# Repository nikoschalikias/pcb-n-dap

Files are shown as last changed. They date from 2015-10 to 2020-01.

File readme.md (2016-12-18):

Pinout
------

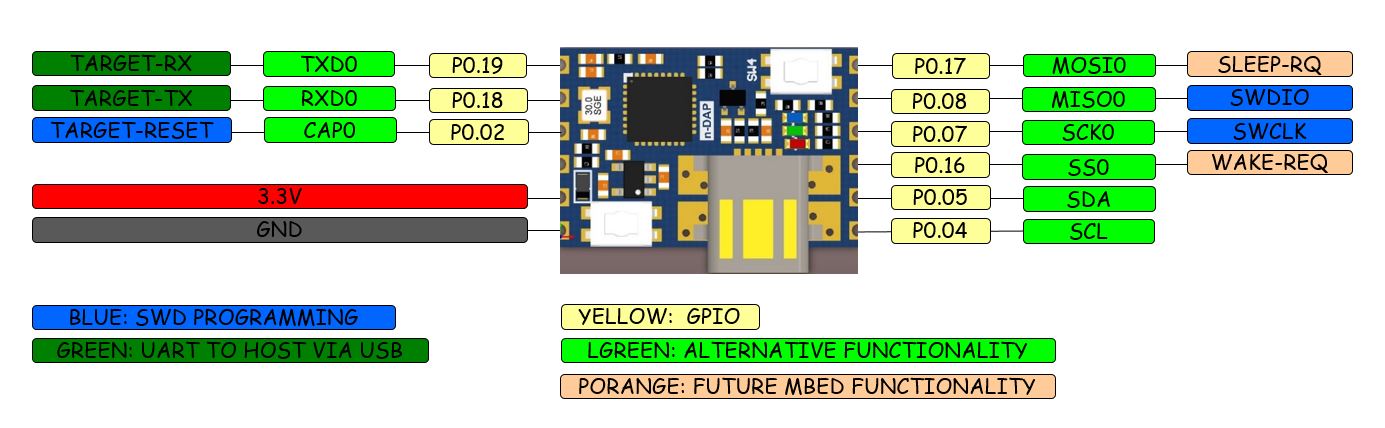
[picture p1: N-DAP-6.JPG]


-   The board has 12 pins, 6 for each side, If the board is used SWD
    only 3 pins for signals and 2 pins for power are needed

Background
----------

LPC11U32 based CMSIS-DAP programming of ARM Cortex devices via SWD.
Appears as a Disk to PC. Tested with mbed firmware.\
Provides **mbed-enable** capability and can be designed-in as an SMD
component or used as external programmer/debuger.\
\
\
\


\
\
\
\
\

Features
--------

<File:N-DAP-3.JPG> <File:N-DAP-2.JPG>

-   Breadboard-able: 1/10 inch connector pitch
-   Solder as SMD component: SMD half pads at 1/10' pitch
-   Robust USB mini connector:

\
\

mbed-enable Firmware
--------------------

### LPC1768

-   [**LPC11U32-Firmware** for communicating with
    LPC1768](https://developer.mbed.org/users/chalikias/code/mbed-HDK/)

\

### LPC812

The same as LPC1768 above\
\
===LPC1114FN28===

-   Firmware to use n-DAP with the non-SMD LPC1114FN28 DIP-28 [Firmware
    LPC1114FN28](https://developer.mbed.org/teams/Switch-Science/wiki/Firmware-LPC1114FN28)

\
===nRF51822===

-   [Seeed studio wiki Arch
    BLE](http://www.seeedstudio.com/wiki/Arch_BLE)
-   [Seeed studio wiki <File:Lpc11u35> nrf51822 if
    mbed.bin.zip](http://www.seeedstudio.com/wiki/File:Lpc11u35_nrf51822_if_mbed.bin.zip)

\
\

Using with mbed-CLI
-------------------

-   Checking the working target setup\

\
\
\* compile\
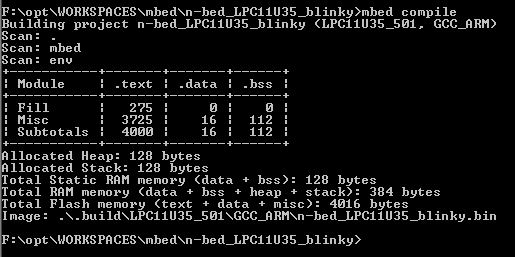
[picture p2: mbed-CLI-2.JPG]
\
\
\* After pressing \[SW4+SW3\], then \[SW3 only\], then \[release
SW3\],CPU is in ISP mode and appears as Disk with name **"CRP
DISABLD"**\
\* Remove previous firmware from CPU flash by deleting the file
**firmware.bin**\
\*The folder should be empty\
\*Then just drag-drop the new compiled .bin to the mbed board. It should
appear as "**firmware.bin**"

\
\

Related articles in this Wiki
-----------------------------

-   []( "wikilink")

\
\

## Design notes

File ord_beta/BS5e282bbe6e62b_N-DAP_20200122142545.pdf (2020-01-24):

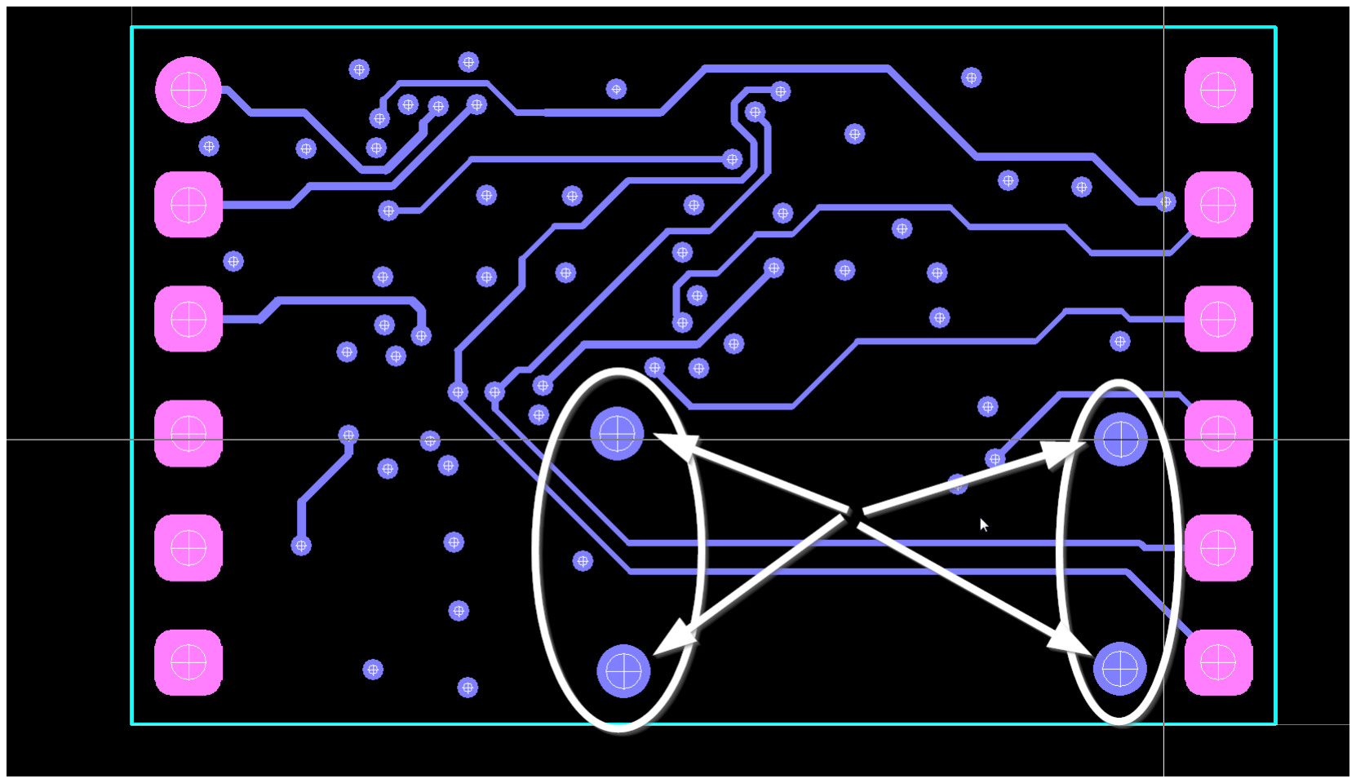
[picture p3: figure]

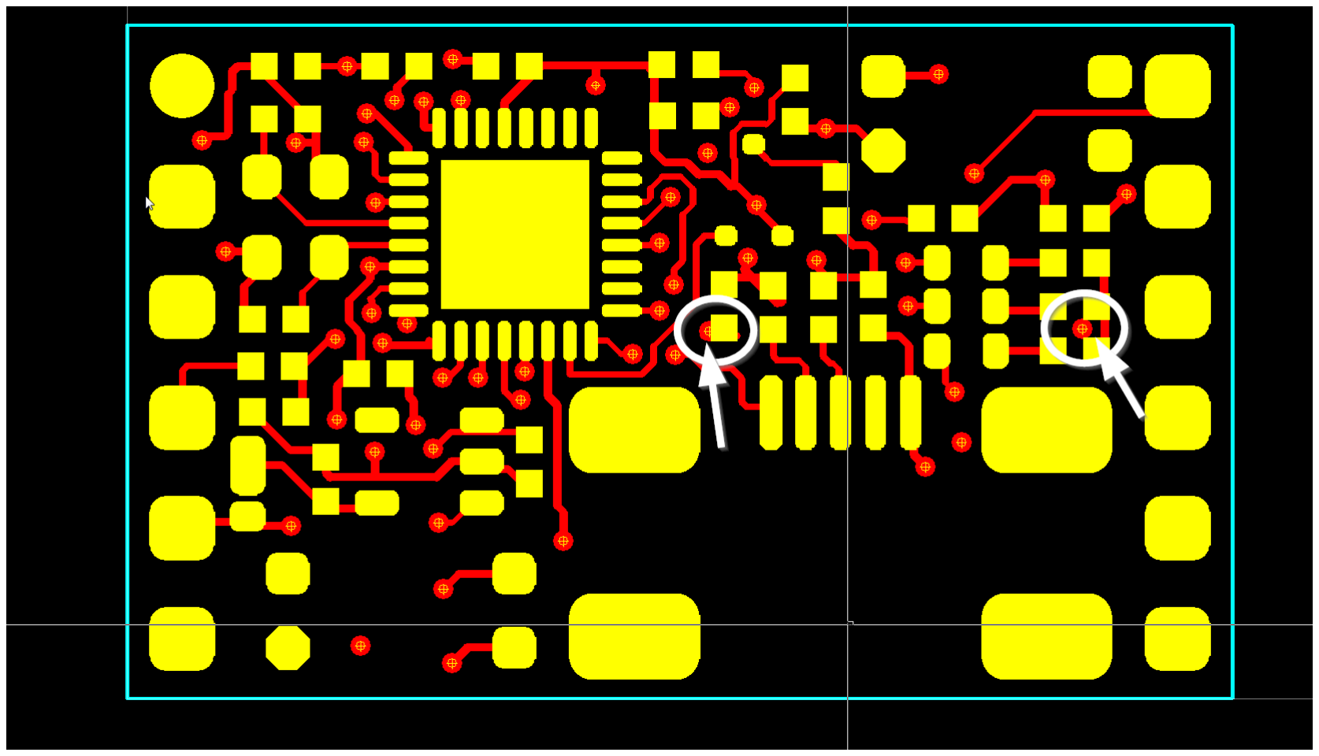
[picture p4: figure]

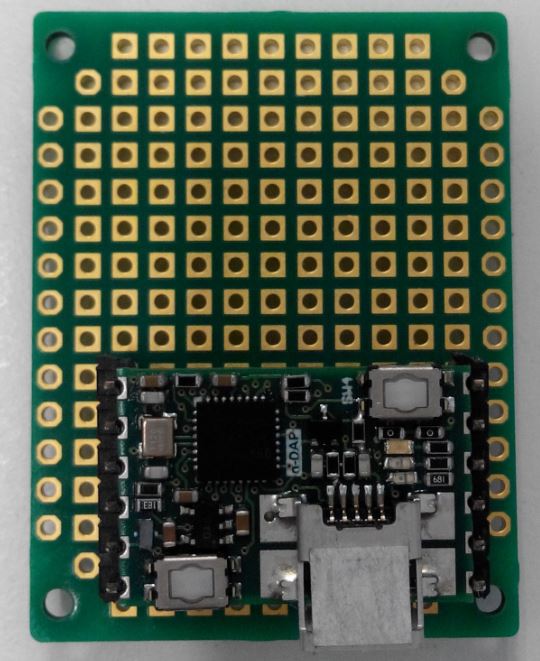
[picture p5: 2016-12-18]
doc/N-DAP-2.JPG

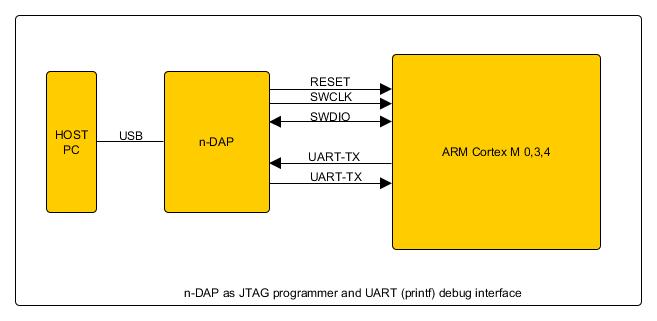
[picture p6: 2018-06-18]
doc/n-dap-programming-block-diagram.jpg

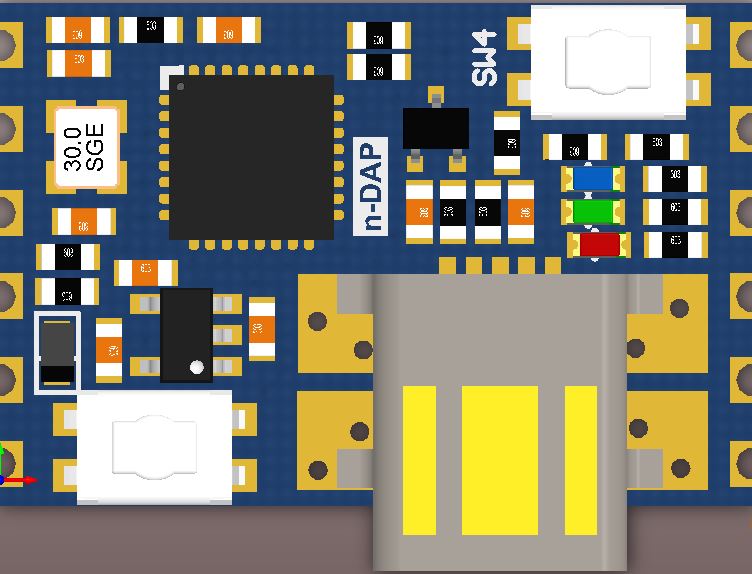
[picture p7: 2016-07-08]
doc/N-DAP-1.JPG

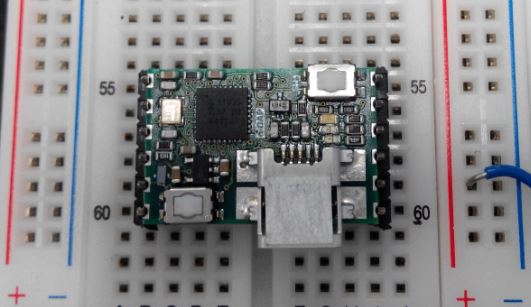
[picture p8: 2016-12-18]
doc/N-DAP-3.JPG

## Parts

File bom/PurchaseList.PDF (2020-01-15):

Item # | Designator | Comment | Footprint | Description | Manufacturer 1 | Manufacturer Part
| | | | | Number 1 | Supplier 1 | | Supplier Stock 1 | Supplier Part Number 1 | Divi der
1 | C1, C4, C5 | 100nF | 0402_CAP | CAPACITOR | Wurth Electronics | 885012105016 | Mouser | EUR | 40946 | 710-885012105016 | 1 | 3 | 108 | 108 | €0.02 | €2.04 | 1
2 | C2, C3 | 18pF | 0402_CAP | CAPACITOR | Walsin Technologies | 0402N180F500CT | Mouser | EUR | 5900 | 791-0402N180F500CT | 1 | 2 | 100 | 100 | €0.04 | €3.59 | 2
3 | C6, C7 | 33pF | 0402_CAP | CAPACITOR | Wurth Electronics | 885012005058 | Mouser | EUR | 34052 | 710-885012005058 | 1 | 2 | 72 | 72 | €0.01 | €1.03 | 3
4 | C8, C10 | 1uF/MLCC | 0402_CAP | CAPACITOR | Taiyo Yuden | JMK105BJ105KP-F | Mouser | EUR | 25442 | 963-JMK105BJ105KP-F | 1 | 2 | 100 | 100 | €0.03 | €2.88 | 4
5 | D1 | LED_RED_0603 | 0603_LED_RED | | Osram Opto | LSQ976-NR-1 | Mouser | EUR | 67675 | 720-LSQ976-NR-1 | 1 | 1 | 100 | 100 | €0.07 | €6.83 | 5
6 | D2 | LED_GRN_0603 | 0603_LED_GRN | | Kingbright | APT1608SGC | Mouser | EUR | 40404 | 604-APT1608SGC | 1 | 1 | 36 | 36 | €0.10 | €3.75 | 6
7 | D3 | LED_BLU_0603 | 0603_LED_BLU | | Osram Opto | LB Q39G-L2OO-35-1 | Mouser | EUR | 58553 | 720-LBQ39GL2N2351 | 1 | 1 | 36 | 36 | €0.27 | €9.70 | 7
8 | D5 | NSR20F30NXT5G | 0603_DIODE-NSR20F30 | SCHOTTKY DIODE 0603 | ON Semiconductor | NSR20F30NXT5G | Mouser | EUR | 115642 | 863-NSR20F30NXT5G | 1.3 | 1 | 36 | 47 | €0.34 | €16.09 | 8
9 | JP2 | USB-MINI-B | USB-MINI-B-HIR-UX60A-MB-5ST-SMALL | | Hirose | UX60A-MB-5ST | Mouser | EUR | 21413 | 798-UX60A-MB-5ST | 1 | 1 | 36 | 36 | €0.67 | €24.06 | 9
10 | Q1 | BSS84,215 | SOT323/SC70-3_SMALL | POWER MOSFET-P SOT23 | Diodes | BSS84W-7-F | Mouser | EUR | 97989 | 621-BSS84W-F | 1 | 1 | 36 | 36 | €0.24 | €8.60 | 10
11 | R1, R3, R4, R9, R14 | 10K | 0402_res | RESISTOR | Vishay | CRCW040210K0FKEDC | Mouser | EUR | 1859432 | 71-CRCW040210K0FKEDC | 1 | 5 | 180 | 180 | €0.01 | €2.10 | 11
12 | R2 | 680R | 0402_res | RESISTOR | Vishay | CRCW0402680RFKEDC | Mouser | EUR | 69395 | 71-CRCW0402680RFKEDC | 1 | 1 | 36 | 36 | €0.03 | €1.04 | 12
13 | R5, R7 | 470R | 0402_RES | RESISTOR | Vishay Semiconductors | CRCW0402470RFKEDC | Mouser | EUR | 84497 | 71-CRCW0402470RFKEDC | 1 | 2 | 100 | 100 | €0.01 | €1.17 | 13
14 | R6, R8 | 33R | 0402_res | RESISTOR | Vishay Semiconductors | CRCW040233R0FKEDC | Mouser | EUR | 135522 | 71-CRCW040233R0FKEDC | 1 | 2 | 100 | 100 | €0.01 | €1.17 | 14
15 | R10 | 1.5K | 0402_res | RESISTOR | Vishay | CRCW04021K50FKEDC | Mouser | EUR | 99619 | 71-CRCW04021K50FKEDC | 1 | 1 | 36 | 36 | €0.03 | €1.04 | 15
16 | R12 | 0R | 0402_res | RESISTOR | Vishay | CRCW04020000Z0EDC | Mouser | EUR | 899812 | 71-CRCW04020000Z0EDC | 1 | 1 | 36 | 36 | €0.01 | €0.52 | 16
17 | R15 | 18K | 0402_RES | RESISTOR | Vishay | CRCW040218K0FKED | Mouser | EUR | 17512 | 71-CRCW0402-18K-E3 | 1 | 1 | 36 | 36 | €0.04 | €1.26 | 17
18 | SW3, SW4 | EVQ-P2202M | BUTTON_4.7x3.5mm | BUTTON TACTILE | Panasonic | EVQ-P2202M | Mouser | EUR | 15015 | 667-EVQ-P2202M | 1 | 2 | 72 | 72 | €0.65 | €46.64 | 18
19 | U1 | LPC11U35FHI33/501 | QFN32_0.5mm_PAD | | NXP Semiconductors | LPC11U35FHI33/501, | Mouser | EUR | 843 | 771-LPC11U35FHI33501 | 1 | 1 | 36 | 36 | €3.44 | €123.84 | 19
20 | U2 | TPS78233 | SOT23-5_0.95mm-NOSILK | | Texas Instruments | TPS78233DDCR | Mouser | EUR | 27457 | 595-TPS78233DDCR | 1 | 1 | 36 | 36 | €0.60 | €21.67 | 20
21 | Y1 | 12MHz | CRY-SMD4-2.5x2mm | CRYSTAL | TXC | 8Z-12.000MAAJ-T | Mouser | EUR | 930 | 717-8Z-12.000MAAJ-T | 1 | 1 | 36 | 36 | €1.22 | €43.92 | 21

### Supplier

### Currency 1 Quantity Supplier

### Order Qty 1 adjusted

QTY

### Supplier

### Unit Price 1 Adjusted Supplier

### Subtotal 1

## Item #

project: | n-DAP | report created: 11:31 | printed: | 15-Jan-2020 11:31 | G .Total | €322.93 | 8.97025556
production QTY: | 36 | pcs | per board

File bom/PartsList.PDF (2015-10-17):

Quantity | Comment | Description | Footprint | Designator
1 | N-DAP | | N-DAP | B1
3 | 100nF | CAPACITOR | 0603_cap | C1, C4, C5
2 | 18pF | CAPACITOR | 0603_cap | C2, C3
2 | 30pF | CAPACITOR | 0603_cap | C6, C7
2 | 1uF/MLCC | CAPACITOR | 0603_CAP | C8, C10
1 | LED_RED_0603 | | 0603_LED_RED | D1
1 | LED_GRN_0603 | | 0603_LED_GRN | D2
1 | LED_BLU_0603 | | 0603_LED_BLU | D3
1 | NSR20F30NXT5G | DIODE | 0603_DIODE-CDSU101A | D5
1 | USB-MINI-B | | USB-MINI-B-HIR-UX60A-MB-5ST | JP2
1 | BSS84,215 | POWER MOSFET-P SOT23 | SOT323/SC70-3_SMALL | Q1
4 | 10K | RESISTOR | 0603_res | R1, R3, R4, R14
1 | 680R | RESISTOR | 0603_res | R2
2 | 470R | RESISTOR | 0603_res | R5, R7
2 | 33R | RESISTOR | 0603_res | R6, R8
1 | 1.5K | RESISTOR | 0603_res | R10
2 | 0R | RESISTOR | 0603_res | R12, R13
1 | 18K | RESISTOR | 0603_res | R15
2 | EVQ-P2202M | BUTTON TACTILE | BUTTON_4.7x3.5mm | SW3, SW4
1 | LPC11U35FHI33/501 | | QFN32_0.5mm_PAD | U1
1 | NCP702N | | SOT23-5_0.95mm-NOSILK | U2
1 | 12MHz | CRYSTAL | CRY-SMD4-2.5x2mm | Y1

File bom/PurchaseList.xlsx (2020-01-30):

Item # | Designator | Comment | Footprint | Description | Manufacturer 1 | Manufacturer Part Number 1 | Supplier 1 | Supplier Currency 1 | Supplier Stock 1 | Supplier Part Number 1 | Divider | Quantity | Supplier Order Qty 1 | adjusted QTY | Supplier Unit Price 1 | Adjusted Supplier Subtotal 1 | Item #
1 | C1, C4, C5 | 100nF | 0402_CAP | CAPACITOR | Wurth Electronics | 885012105016 | Mouser | EUR | 14550 | 710-885012105016 | 1 | 3 | 108 | 108 | €0.02 | €2.06 | 1
2 | C2, C3 | 18pF | 0402_CAP | CAPACITOR | Walsin Technologies | 0402N180F500CT | Mouser | EUR | 5760 | 791-0402N180F500CT | 1 | 2 | 100 | 100 | €0.04 | €3.63 | 2
3 | C6, C7 | 33pF | 0402_CAP | CAPACITOR | Wurth Electronics | 885012005058 | Mouser | EUR | 33732 | 710-885012005058 | 1 | 2 | 72 | 72 | €0.01 | €1.04 | 3
4 | C8, C10 | 1uF/MLCC | 0402_CAP | CAPACITOR | Taiyo Yuden | JMK105BJ105KP-F | Mouser | EUR | 9007 | 963-JMK105BJ105KP-F | 1 | 2 | 100 | 100 | €0.03 | €2.90 | 4
5 | D1 | LED_RED_0603 | 0603_LED_RED |  | Osram Opto | LSQ976-NR-1 | Mouser | EUR | 55905 | 720-LSQ976-NR-1 | 1 | 1 | 100 | 100 | €0.07 | €6.89 | 5
6 | D2 | LED_GRN_0603 | 0603_LED_GRN |  | Kingbright | APT1608SGC | Mouser | EUR | 85016 | 604-APT1608SGC | 1 | 1 | 36 | 36 | €0.11 | €3.79 | 6
7 | D3 | LED_BLU_0603 | 0603_LED_BLU |  | Osram Opto | LB Q39G-L2OO-35-1 | Mouser | EUR | 57670 | 720-LBQ39GL2N2351 | 1 | 1 | 36 | 36 | €0.27 | €9.80 | 7
8 | D5 | NSR20F30NXT5G | 0603_DIODE-NSR20F30 | SCHOTTKY DIODE 0603 | ON Semiconductor | NSR20F30NXT5G | Mouser | EUR | 112788 | 863-NSR20F30NXT5G | 1.3 | 1 | 36 | 47 | €0.35 | €16.24 | 8
9 | JP2 | USB-MINI-B | USB-MINI-B-HIR-UX60A-MB-5ST-SMALL |  | Hirose | UX60A-MB-5ST | Mouser | EUR | 18449 | 798-UX60A-MB-5ST | 1 | 1 | 36 | 36 | €0.67 | €24.29 | 9
10 | Q1 | BSS84,215 | SOT323/SC70-3_SMALL | POWER MOSFET-P SOT23 | Diodes | BSS84W-7-F | Mouser | EUR | 94693 | 621-BSS84W-F | 1 | 1 | 36 | 36 | €0.24 | €8.69 | 10
11 | R1, R3, R4, R9, R14 | 10K | 0402_res | RESISTOR | Vishay | CRCW040210K0FKEDC | Mouser | EUR | 1804342 | 71-CRCW040210K0FKEDC | 1 | 5 | 180 | 180 | €0.01 | €2.12 | 11
12 | R2 | 680R | 0402_res | RESISTOR | Vishay | CRCW0402680RFKEDC | Mouser | EUR | 68280 | 71-CRCW0402680RFKEDC | 1 | 1 | 36 | 36 | €0.03 | €1.04 | 12
13 | R5, R7 | 470R | 0402_RES | RESISTOR | Vishay Semiconductors | CRCW0402470RFKEDC | Mouser | EUR | 83450 | 71-CRCW0402470RFKEDC | 1 | 2 | 100 | 100 | €0.01 | €1.18 | 13
14 | R6, R8 | 33R | 0402_res | RESISTOR | Vishay Semiconductors | CRCW040233R0FKEDC | Mouser | EUR | 131140 | 71-CRCW040233R0FKEDC | 1 | 2 | 100 | 100 | €0.01 | €1.18 | 14
15 | R10 | 1.5K | 0402_res | RESISTOR | Vishay | CRCW04021K50FKEDC | Mouser | EUR | 88605 | 71-CRCW04021K50FKEDC | 1 | 1 | 36 | 36 | €0.03 | €1.04 | 15
16 | R12 | 0R | 0402_res | RESISTOR | Vishay | CRCW04020000Z0EDC | Mouser | EUR | 857327 | 71-CRCW04020000Z0EDC | 1 | 1 | 36 | 36 | €0.01 | €0.52 | 16
17 | R15 | 18K | 0402_RES | RESISTOR | Vishay | CRCW040218K0FKED | Mouser | EUR | 16077 | 71-CRCW0402-18K-E3 | 1 | 1 | 36 | 36 | €0.04 | €1.27 | 17
18 | SW3, SW4 | EVQ-P2202M | BUTTON_4.7x3.5mm | BUTTON TACTILE | Panasonic | EVQ-P2202M | Mouser | EUR | 14899 | 667-EVQ-P2202M | 1 | 2 | 72 | 72 | €0.65 | €47.08 | 18
19 | U1 | LPC11U35FHI33/501 | QFN32_0.5mm_PAD |  | NXP Semiconductors | LPC11U35FHI33/501, | Mouser | EUR | 806 | 771-LPC11U35FHI33501 | 1 | 1 | 36 | 36 | €3.47 | €124.92 | 19
20 | U2 | TPS78233 | SOT23-5_0.95mm-NOSILK |  | Texas Instruments | TPS78233DDCR | Mouser | EUR | 27275 | 595-TPS78233DDCR | 1 | 1 | 36 | 36 | €0.61 | €21.88 | 20
21 | Y1 | 12MHz | CRY-SMD4-2.5x2mm | CRYSTAL | TXC | 8Z-12.000MAAJ-T | Mouser | EUR | 478 | 717-8Z-12.000MAAJ-T | 1 | 1 | 36 | 36 | €1.23 | €44.28 | 21
project: |  | n-DAP |  | report created: | 21:05 |  |  | printed: |  | 2020-01-30 21:05 |  |  |  |  | G .Total | €325.86 | 9.051531944
 |  |  |  |  |  |  |  |  |  | production QTY: |  |  | 36 |  |  | pcs | per board

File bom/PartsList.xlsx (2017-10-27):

Quantity | Comment | Description | Footprint | Designator
3 | 100nF | CAPACITOR | 0603_CAP_SMALL | C1, C4, C5
2 | 18pF | CAPACITOR | 0603_CAP_SMALL | C2, C3
2 | 33pF | CAPACITOR | 0603_CAP_SMALL | C6, C7
2 | 1uF/MLCC | CAPACITOR | 0603_CAP_SMALL | C8, C10
1 | LED_RED_0603 |  | 0603_LED_RED | D1
1 | LED_GRN_0603 |  | 0603_LED_GRN | D2
1 | LED_BLU_0603 |  | 0603_LED_BLU | D3
1 | NSR20F30NXT5G | SCHOTTKY DIODE 0603 | 0603_DIODE-NSR20F30 | D5
1 | USB-MINI-B |  | USB-MINI-B-HIR-UX60A-MB-5ST-SMALL | JP2
1 | BSS84,215 | POWER MOSFET-P SOT23 | SOT323/SC70-3_SMALL | Q1
5 | 10K | RESISTOR | 0603_res_SMALL | R1, R3, R4, R9, R14
1 | 680R | RESISTOR | 0603_res_SMALL | R2
2 | 470R | RESISTOR | 0603_res_SMALL | R5, R7
2 | 33R | RESISTOR | 0603_res_SMALL | R6, R8
1 | 1.5K | RESISTOR | 0603_res_SMALL | R10
1 | 0R | RESISTOR | 0603_res_SMALL | R12
1 | 18K | RESISTOR | 0603_res_SMALL | R15
2 | EVQ-P2202M | BUTTON TACTILE | BUTTON_4.7x3.5mm | SW3, SW4
1 | LPC11U35FHI33/501 |  | QFN32_0.5mm_PAD | U1
1 | TPS78233 |  | SOT23-5_0.95mm-NOSILK | U2
1 | 12MHz | CRYSTAL | CRY-SMD4-2.5x2mm | Y1

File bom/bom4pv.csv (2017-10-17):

Quantity | Designator | Comment
3 | C1, C4, C5 | 100nF
2 | C2, C3 | 18pF
2 | C6, C7 | 33pF
2 | C8, C10 | 1uF/MLCC
1 | D1 | LED_RED_0603
1 | D2 | LED_GRN_0603
1 | D3 | LED_BLU_0603
1 | D5 | NSR20F30NXT5G
1 | JP2 | USB-MINI-B
1 | Q1 | BSS84,215
5 | R1, R3, R4, R9, R14 | 10K
1 | R2 | 680R
2 | R5, R7 | 470R
2 | R6, R8 | 33R
1 | R10 | 1.5K
1 | R12 | 0R
1 | R15 | 18K
2 | SW3, SW4 | EVQ-P2202M
1 | U1 | LPC11U35FHI33/501
1 | U2 | TPS78233
1 | Y1 | 12MHz

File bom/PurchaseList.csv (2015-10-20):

Item # | Designator | Comment | Footprint | #Column Name Error:Manufacturer | Description | S.Description | Manufacturer 1 | Manufacturer Part Number 1 | Supplier 1 | Supplier Currency 1 | Supplier Stock 1 | Supplier Part Number 1 | Divider | Quantity | Supplier Order Qty 1 | adjusted QTY | Supplier Unit Price 1 | Adjusted Supplier Subtotal 1 | Item #
1 | D1 | LED_RED_0603 | 0603_LED_RED |  |  | Oosls L29k-G1j2-1-z Q65110a1757 Led Othe | Osram Opto | LS L29K-G1J2-1-Z | Octopart | EUR | 74224 | Mouser - 720-LSL29K-G1J2-1-Z | 1 | 1 | 20 | 20 | €0.12 | €2.33 | 1
2 | C1, C4, C5 | 100nF | 0603_cap |  | CAPACITOR | Multilayer Ceramic Capacitors MLCC - SMD/SMT 50volts 0.1uF 10% X7R | AVX | 06035C104KAT2A | Mouser | EUR | 482487 | 581-06035C104KAT2A | 1 | 3 | 100 | 100 | €0.03 | €2.70 | 2
3 | C2, C3 | 18pF | 0603_cap |  | CAPACITOR | Multilayer Ceramic Capacitors MLCC - SMD/SMT 25volts 18pF 2% C0G | AVX | 02013A180GAT2A | Mouser | EUR | 28018 | 581-02013A180GAT2A | 1 | 2 | 40 | 40 | €0.09 | €3.64 | 3
4 | C6, C7 | 33pF | 0603_cap |  | CAPACITOR | Multilayer Ceramic Capacitors MLCC - SMD/SMT 50volts 33pF 5% C0G | AVX | 06035A330JAT2A | Mouser | EUR | 48580 | 581-06035A330J | 1 | 2 | 100 | 100 | €0.02 | €2.00 | 4
5 | C8, C10 | 1uF/MLCC | 0603_CAP |  | CAPACITOR | Multilayer Ceramic Capacitors MLCC - SMD/SMT 0603 1.0uF 16volts X7R 10% | Murata Electronics | GCM188R71C105KA64D | Mouser | EUR | 196748 | 81-GCM188R71C105K64D | 1 | 2 | 40 | 40 | €0.15 | €6.04 | 5
6 | D2 | LED_GRN_0603 | 0603_LED_GRN |  |  | Standard LEDs - SMD Green, 570nm 10mcd, 2mA | OSRAM Opto Semiconductors | LG L29K-F2J1-24-Z | Mouser | EUR | 31083 | 720-LGL29KF2J124Z | 1 | 1 | 20 | 20 | €0.12 | €2.42 | 6
7 | D3 | LED_BLU_0603 | 0603_LED_BLU |  |  | Standard LEDs - SMD Blue, 470nm 45mcd, 5mA | OSRAM Opto Semiconductors | LB Q39G-L2N2-35-1 | Mouser | EUR | 108800 | 720-LBQ39GL2N2351 | 1 | 1 | 20 | 20 | €0.12 | €2.42 | 7
8 | D5 | NSR20F30NXT5G | 0603_DIODE-CDSU101A |  | DIODE | Schottky Diodes & Rectifiers 0603 FC SCHOTTKY DIODES | ON Semiconductor | NSR20F30NXT5G | Mouser | EUR | 32431 | 863-NSR20F30NXT5G | 1 | 1 | 20 | 20 | €0.34 | €6.70 | 8
9 | JP2 | USB-MINI-B | USB-MINI-B-HIR-UX60A-MB-5ST |  |  | USB Connectors MINI B RECEPT RA SMT W/O POST | Hirose Connector | UX60A-MB-5ST | Mouser | EUR | 8795 | 798-UX60A-MB-5ST | 1 | 1 | 20 | 20 | €0.69 | €13.74 | 9
10 | Q1 | BSS84,215 | SOT323/SC70-3_SMALL |  | POWER MOSFET-P SOT23 | MOSFET -50V 200mW | Diodes Incorporated | BSS84W-7-F | Mouser | EUR | 13597 | 621-BSS84W-F | 1 | 1 | 20 | 20 | €0.24 | €4.84 | 10
11 | R1, R3, R4, R14 | 10K | 0603_res |  | RESISTOR | Thick Film Resistors - SMD 0603 10Kohms 1% Tol | Panasonic | ERJ-3EKF1002V | Mouser | EUR | 1822371 | 667-ERJ-3EKF1002V | 1 | 4 | 100 | 100 | €0.01 | €0.80 | 11
12 | R10 | 1.5K | 0603_res |  | RESISTOR | Thick Film Resistors - SMD 0603 1.5Kohms 1% Tol | Panasonic | ERJ-3EKF1501V | Mouser | EUR | 183199 | 667-ERJ-3EKF1501V | 1 | 1 | 20 | 20 | €0.01 | €0.26 | 12
13 | R12, R13 | 0R | 0603_res |  | RESISTOR | Thick Film Resistors - SMD 0603 Zero Ohms | Panasonic | ERJ-3GEY0R00V | Mouser | EUR | 1222167 | 667-ERJ-3GEY0R00V | 1 | 2 | 40 | 40 | €0.01 | €0.44 | 13
14 | R15 | 18K | 0603_res |  | RESISTOR | Thick Film Resistors - SMD 0603 18Kohms 5% Tol | Panasonic | ERJ-3GEYJ183V | Mouser | EUR | 114431 | 667-ERJ-3GEYJ183V | 1 | 1 | 20 | 20 | €0.02 | €0.36 | 14
15 | R2 | 680R | 0603_res |  | RESISTOR | Thin Film Resistors - SMD 1/16W 680ohm 0.5% 25ppm | Susumu | RR0816P-681-D | Mouser | EUR | 17419 | 754-RR0816P-681D | 1 | 1 | 20 | 20 | €0.05 | €0.92 | 15
16 | R5, R7 | 470R | 0603_res |  | RESISTOR | Thick Film Resistors - SMD 0603 470ohms 1% Tol | Panasonic | ERJ-3EKF4700V | Mouser | EUR | 136285 | 667-ERJ-3EKF4700V | 1 | 2 | 40 | 40 | €0.01 | €0.56 | 16
17 | R6, R8 | 33R | 0603_res |  | RESISTOR | Thick Film Resistors - SMD 0603 33.0ohms 1% Tol | Panasonic | ERJ-3EKF33R0V | Mouser | EUR | 323332 | 667-ERJ-3EKF33R0V | 1 | 2 | 40 | 40 | €0.01 | €0.56 | 17
18 | SW3, SW4 | EVQ-P2202M | BUTTON_4.7x3.5mm |  | BUTTON TACTILE | Tactile Switches 4.7x3.5mm SMD Light Touch Switch | Panasonic | EVQ-P2202M | Mouser | EUR | 3171 | 667-EVQ-P2202M | 1 | 2 | 40 | 40 | €0.59 | €23.56 | 18
19 | U1 | LPC11U35FHI33/501 | QFN32_0.5mm_PAD |  |  | ARM Microcontrollers - MCU 32-bit ARM Cortex-M0 64KB Flash 12KB SRAM | NXP Semiconductors | LPC11U35FHI33/501, | Mouser | EUR | 836 | 771-LPC11U35FHI33501 | 1 | 1 | 20 | 20 | €3.29 | €65.80 | 19
20 | U2 | TPS78233 | SOT23-5_0.95mm-NOSILK |  |  | LDO Voltage Regulators Sgl Fixed Out LDO 150mA,1uA Quies Crnt | Texas Instruments | TPS78233DDCR | Mouser | EUR | 12587 | 595-TPS78233DDCR | 1 | 1 | 20 | 20 | €0.72 | €14.44 | 20
21 | Y1 | 12MHz | CRY-SMD4-2.5x2mm |  | CRYSTAL | Crystals 12MHz 30ppm 18pF -20C +70C | TXC Corporation | 8Z-12.000MAAJ-T | Mouser | EUR | 2708 | 717-8Z-12.000MAAJ-T | 1 | 1 | 20 | 20 | €1.36 | €27.20 | 21
22 | B1 | N-DAP | N-DAP |  |  |  |  |  |  |  |  |  | 1 | 1 |  | 0 |  | €0.00 | 22
project: |  | n-DAP |  |  | report created: | 20/10/2015 | 14:15:36 |  |  | printed: |  | 20/Oct/2015 14:15 |  |  |  |  | G .Total | €181.73 | 9.08658
 |  |  |  |  |  |  |  |  |  |  |  | production QTY: |  |  | 20 |  |  | pcs | per board

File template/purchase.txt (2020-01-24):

purchase file set done at -20Ja24_163200

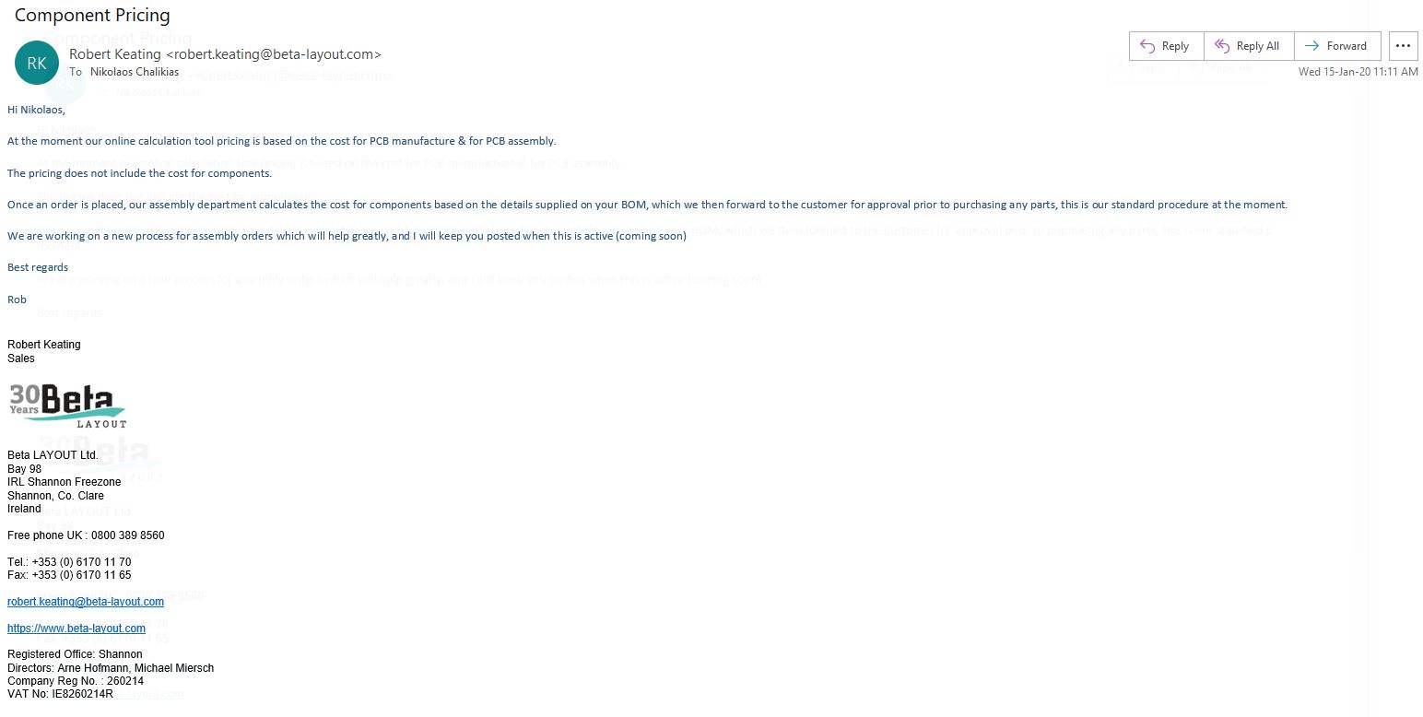
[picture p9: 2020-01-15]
ord_beta/beta-layout-components-pricing.JPG

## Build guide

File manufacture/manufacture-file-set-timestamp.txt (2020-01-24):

manufacturer file set done at -20Ja24_163200

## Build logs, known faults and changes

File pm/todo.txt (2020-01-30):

x submit to cit for PO
x first submission to Beta Layout
x update PCB and resubmit after errors found from Betalayout
(A) Follow up with Betalayout
x Assembly file create and send with 3D file
(A) Tidy up the outjob file PurchaseList, remove the assembly and tidy up somewhere else

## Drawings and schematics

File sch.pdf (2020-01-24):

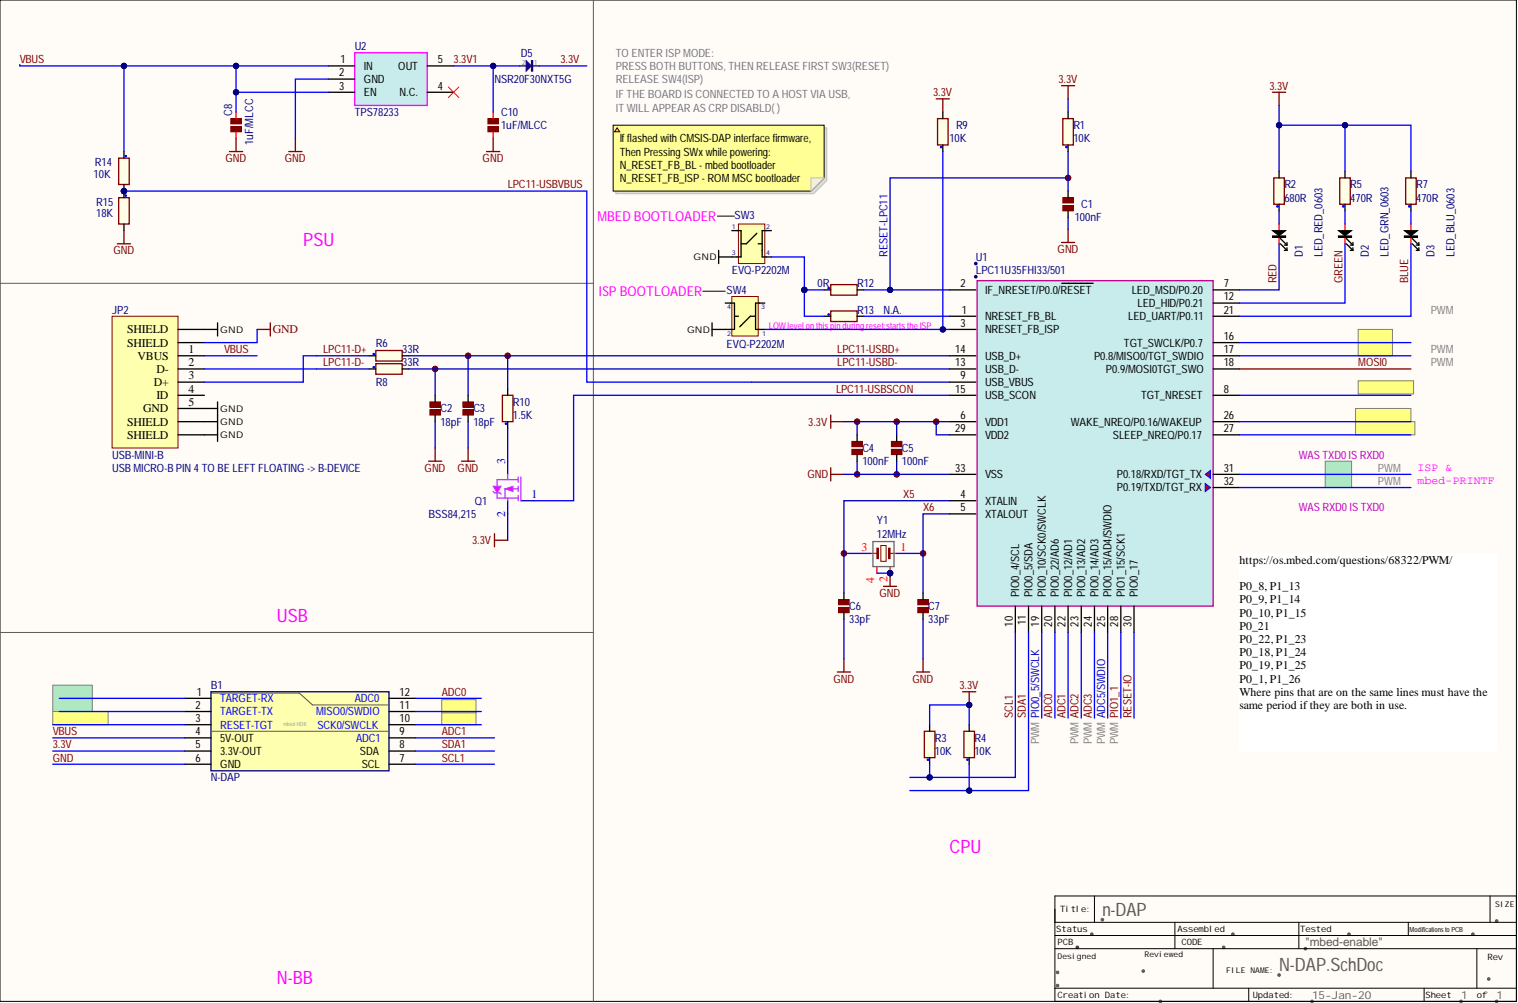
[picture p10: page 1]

TO ENTER ISP MODE:
PRESS BOTH BUTTONS, THEN RELEASE FIRST SW3(RESET)
RELEASE SW4(ISP)
IF THE BOARD IS CONNECTED TO A HOST VIA USB,
IT WILL APPEAR AS CRP DISABLD( )

If flashed with CMSIS-DAP interface firmware,
Then Pressing SWx while powering:
N_RESET_FB_BL - mbed bootloader
N_RESET_FB_ISP - ROM MSC bootloader

LOW level on this pin during reset:starts the ISP

SHIELD
USB-MINI-B
USB MICRO-B PIN 4 TO BE LEFT FLOATING -> B-DEVICE

1 | VDD2 29 VDD1 6

C4 | C5 | SLEEP-REQ

https://os.mbed.com/questions/68322/PWM/

Title: | n-DAP | SIZE

Status | Assembled | Tested | Modifications to PCB
PCB | CODE | "mbed-enable"
Designed Reviewed | N-DAP.SchDoc FILE NAME: | Rev

Creation Date: | Updated: 15-Jan-20 | Sheet 1 of 1

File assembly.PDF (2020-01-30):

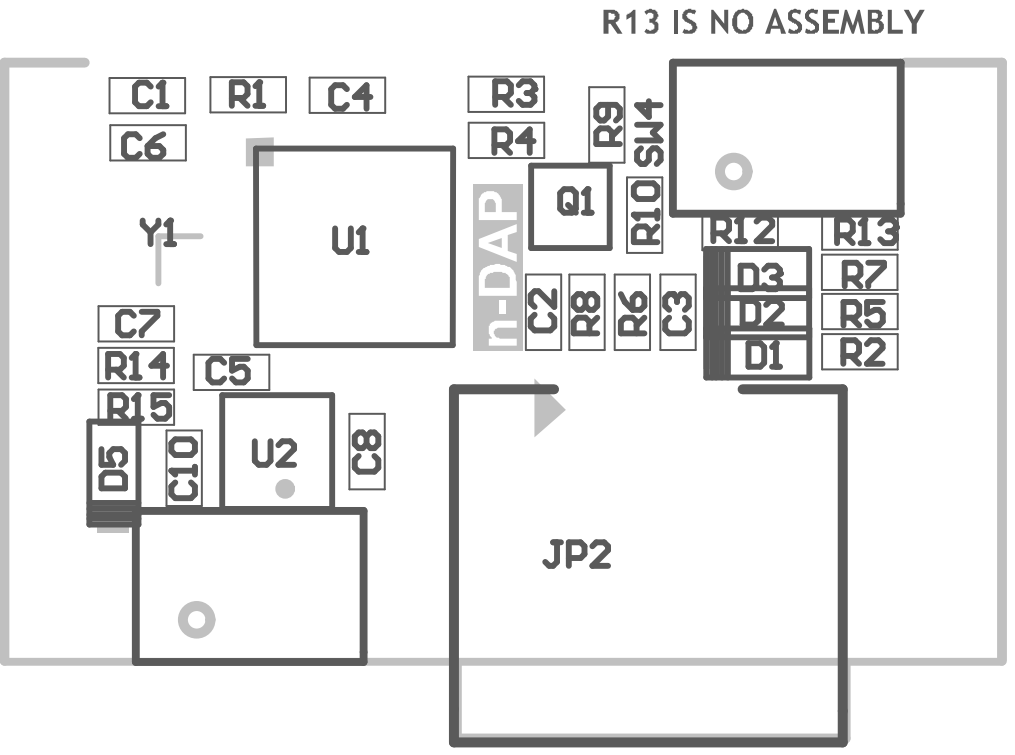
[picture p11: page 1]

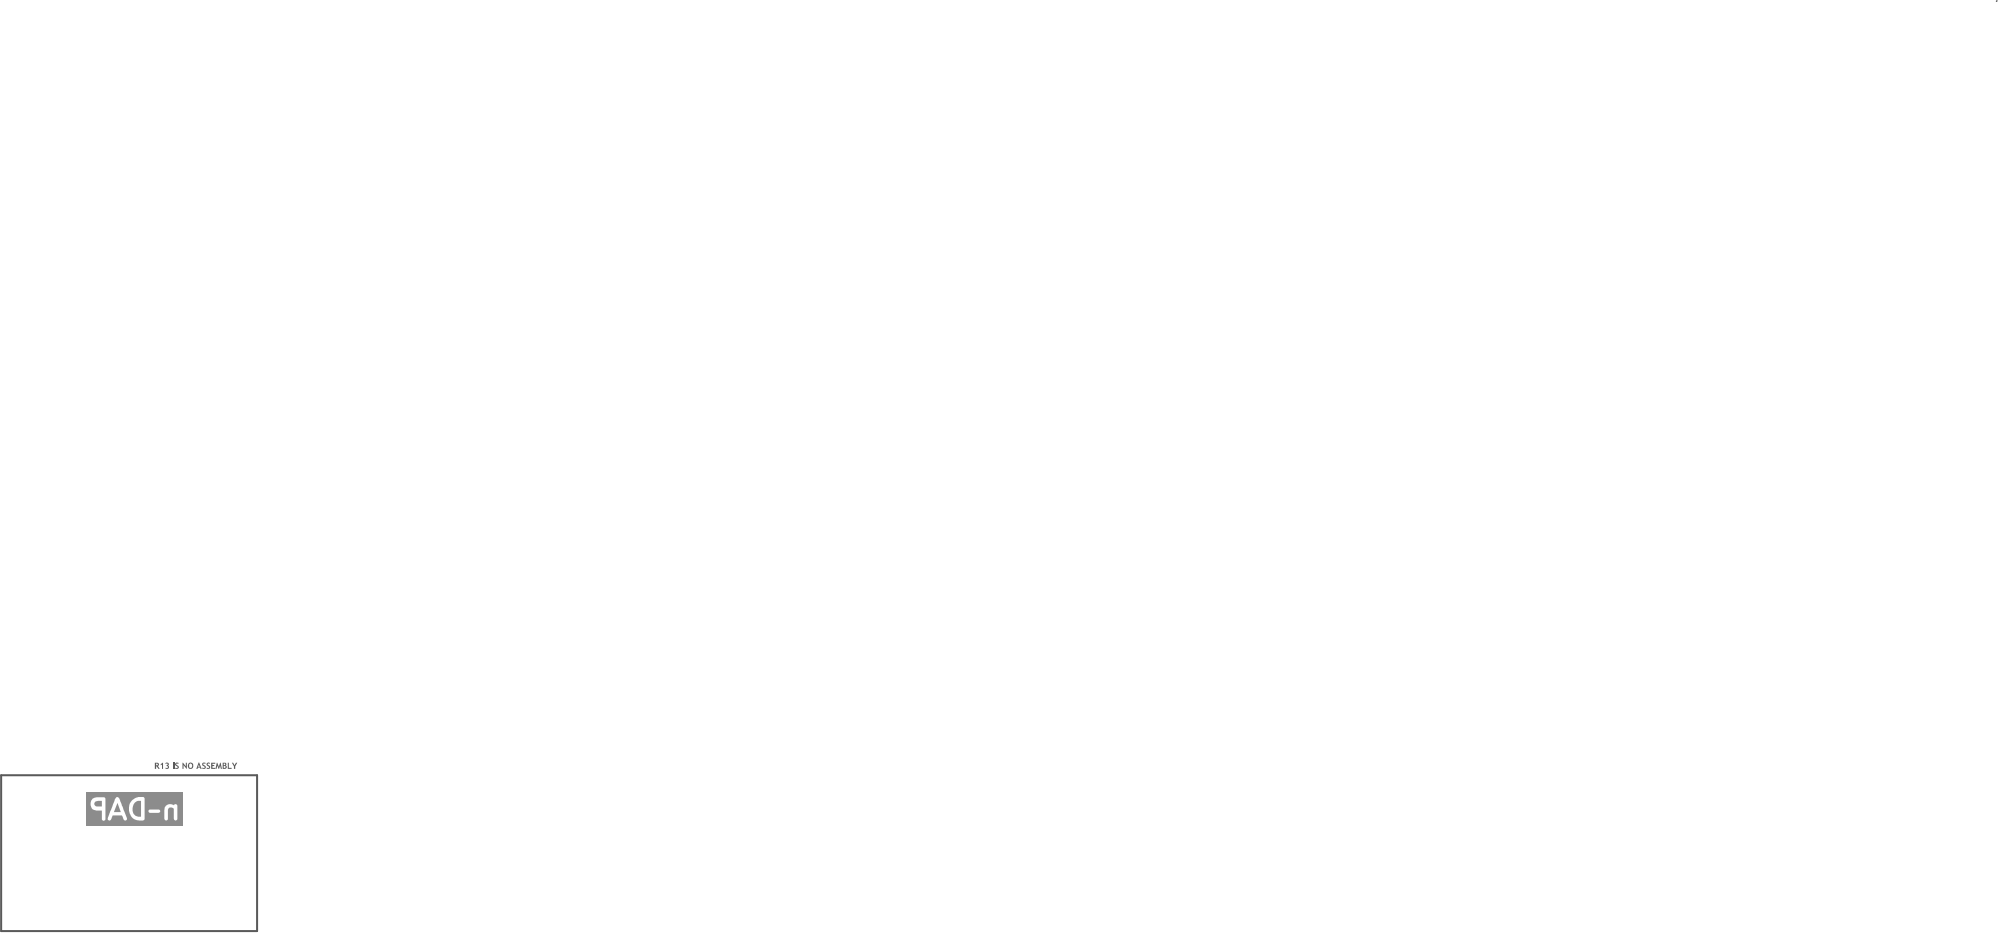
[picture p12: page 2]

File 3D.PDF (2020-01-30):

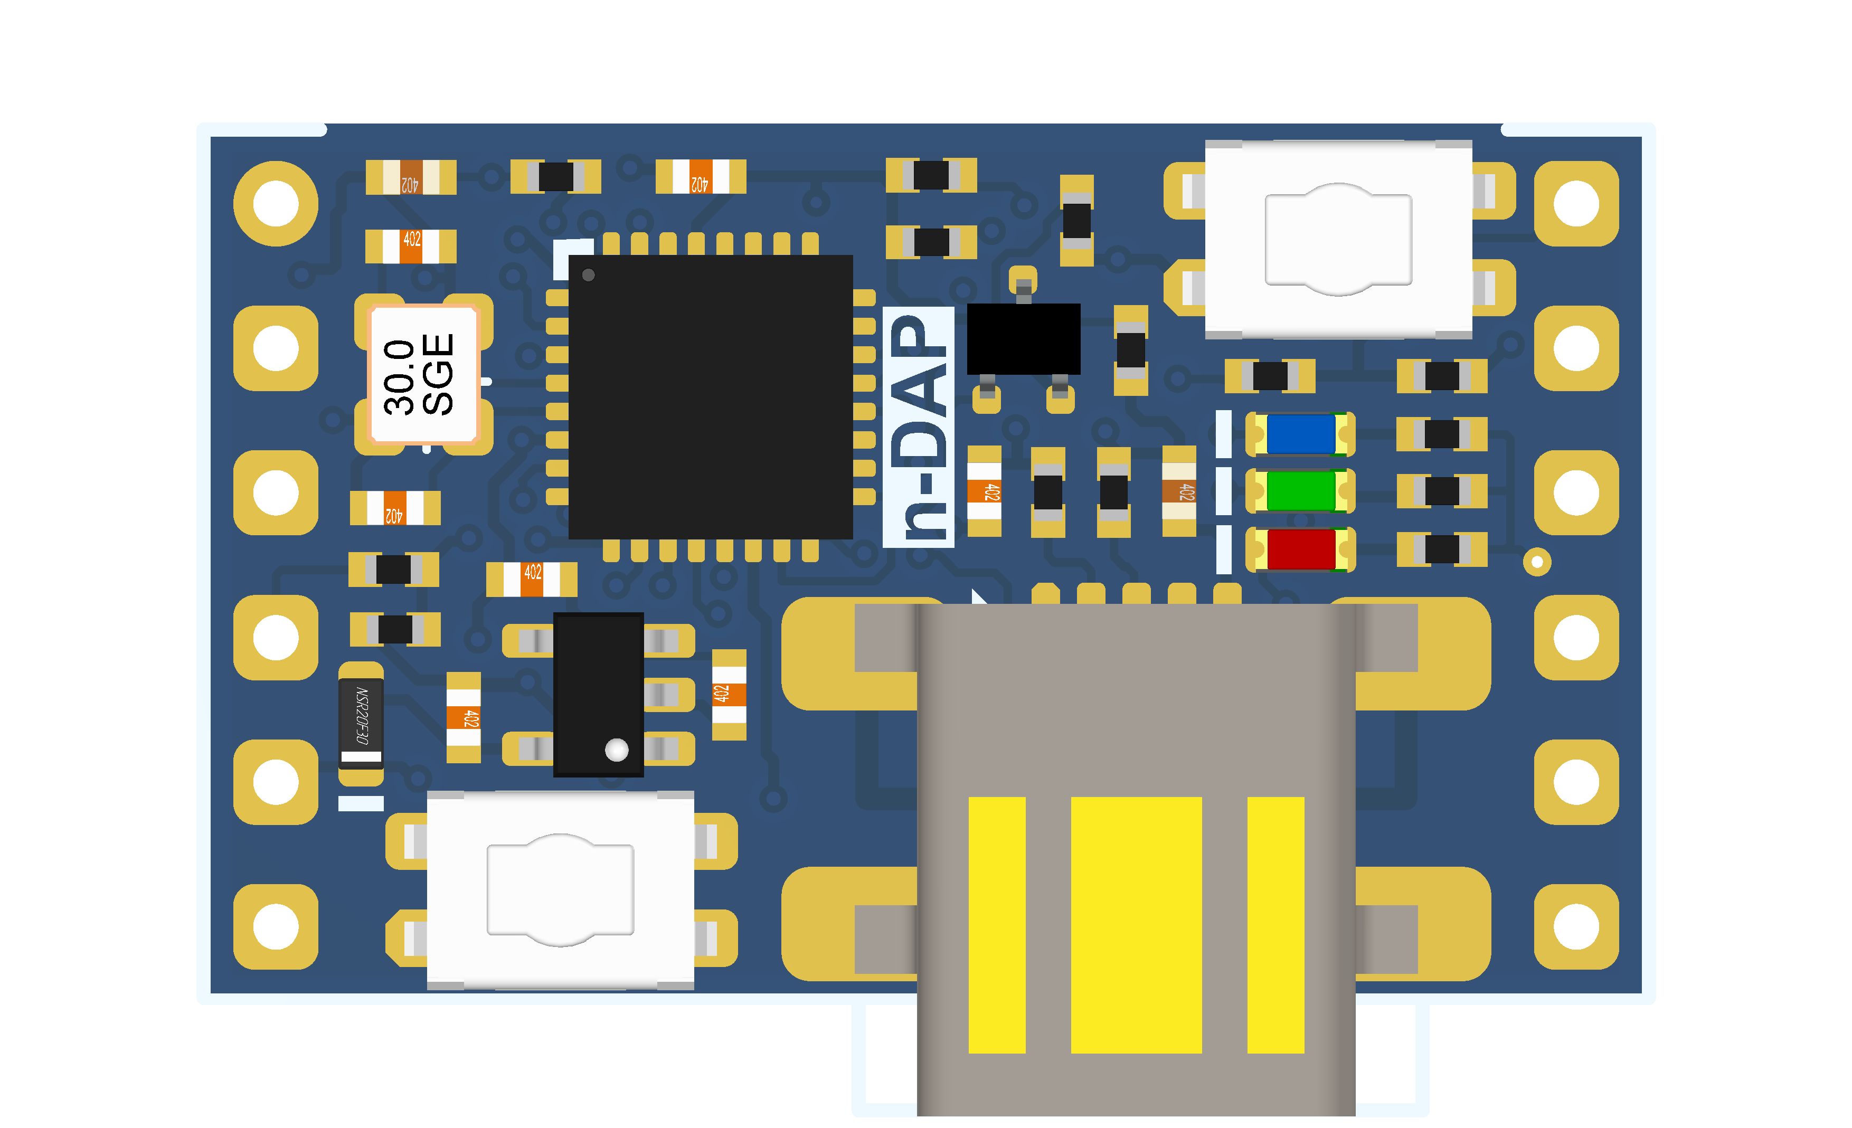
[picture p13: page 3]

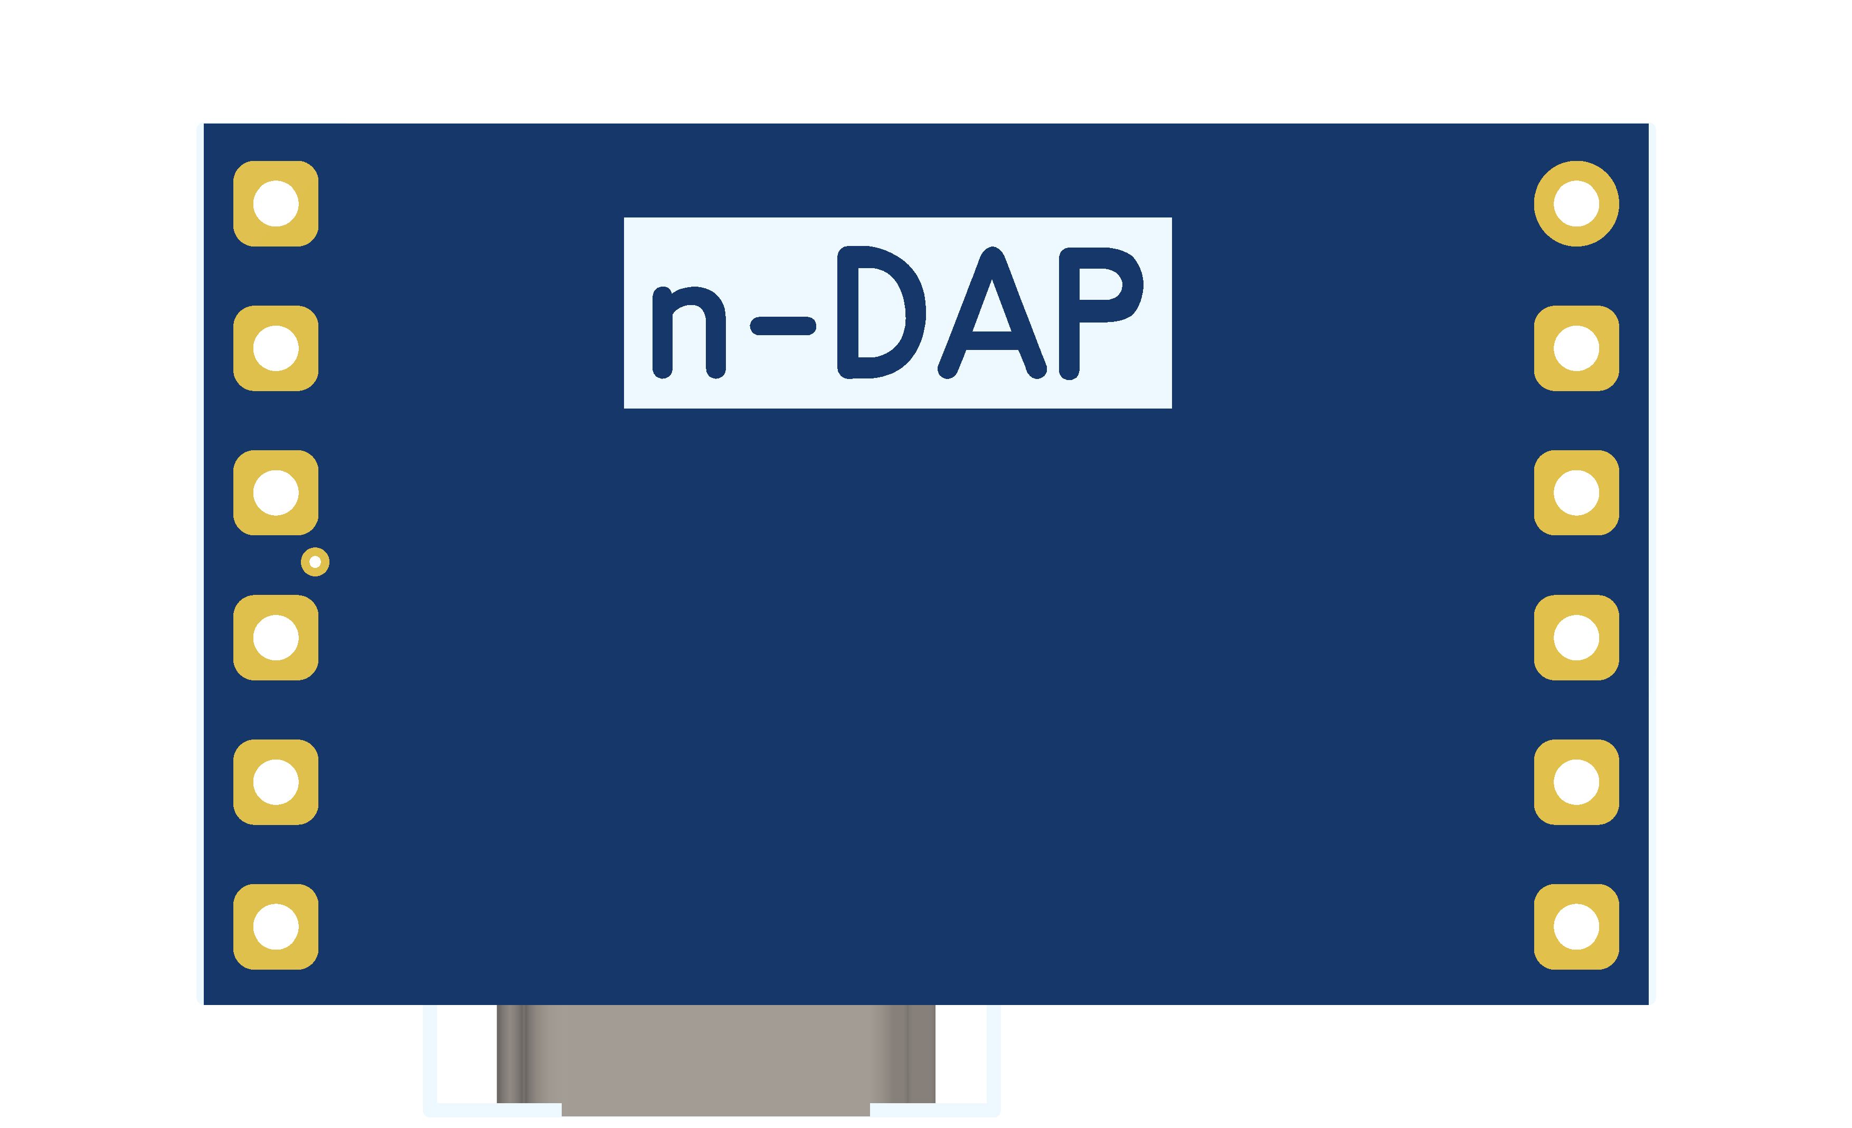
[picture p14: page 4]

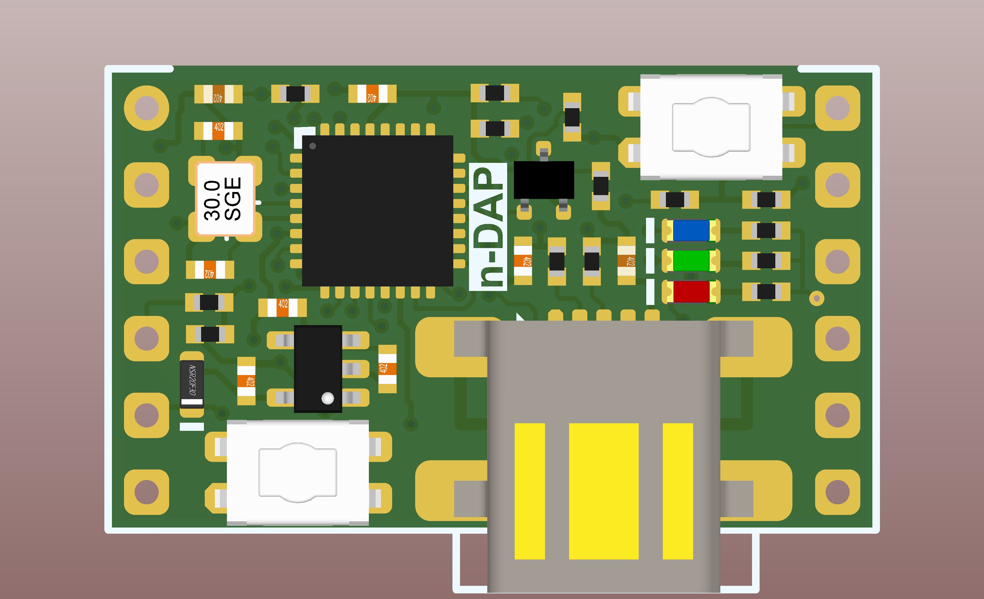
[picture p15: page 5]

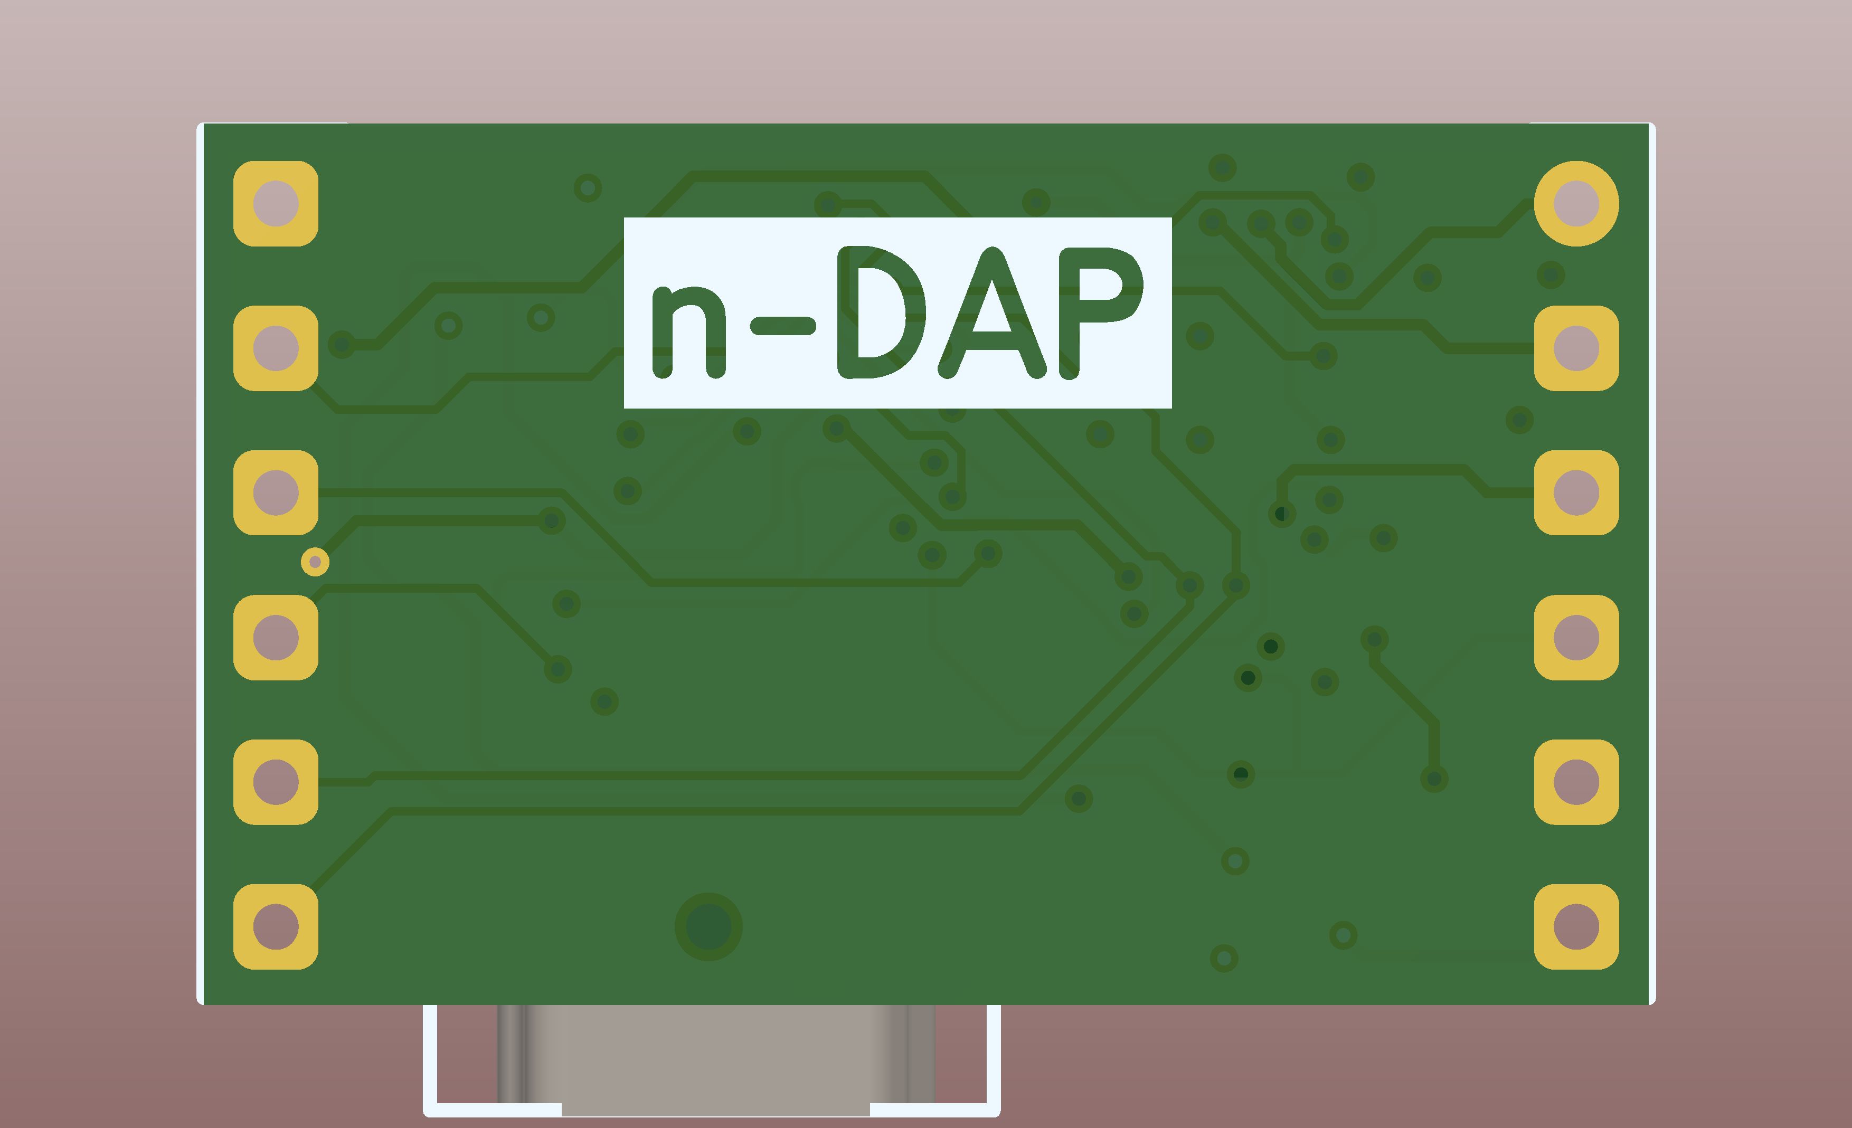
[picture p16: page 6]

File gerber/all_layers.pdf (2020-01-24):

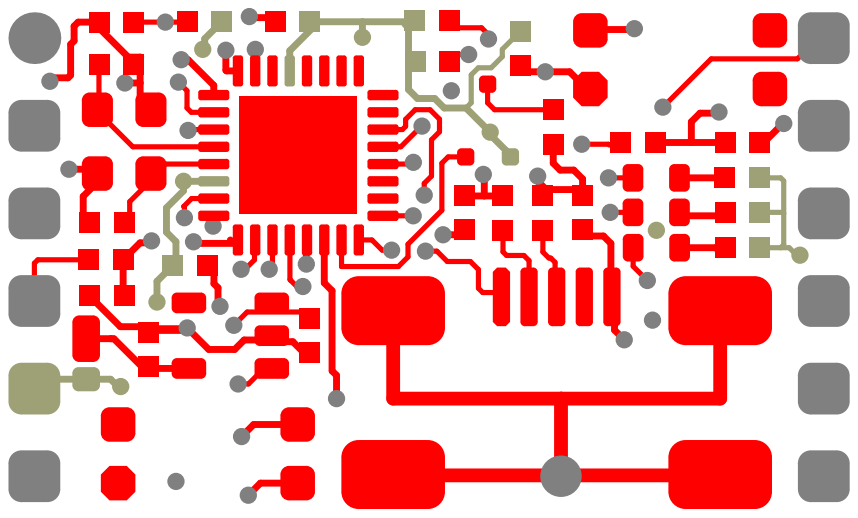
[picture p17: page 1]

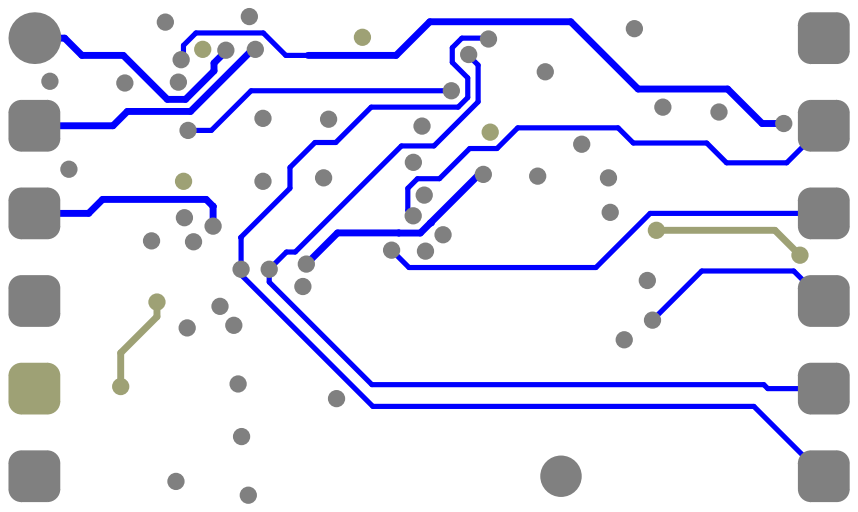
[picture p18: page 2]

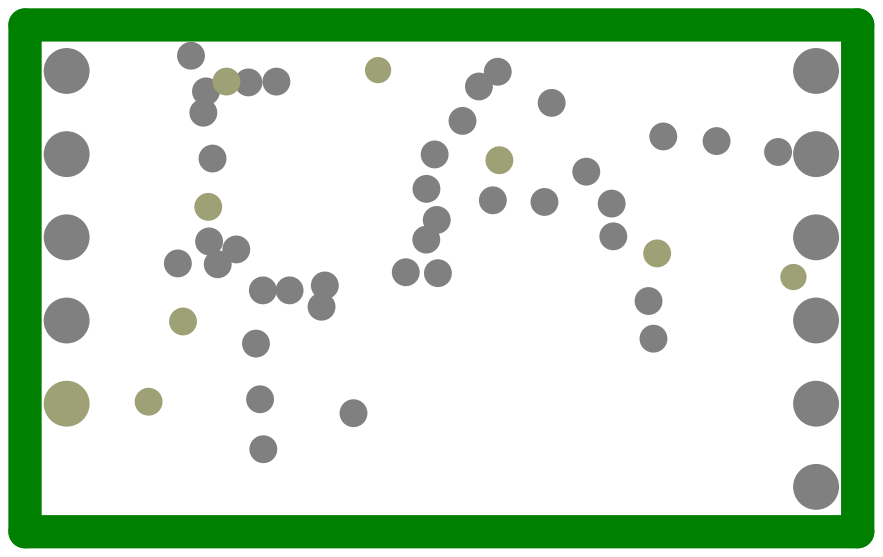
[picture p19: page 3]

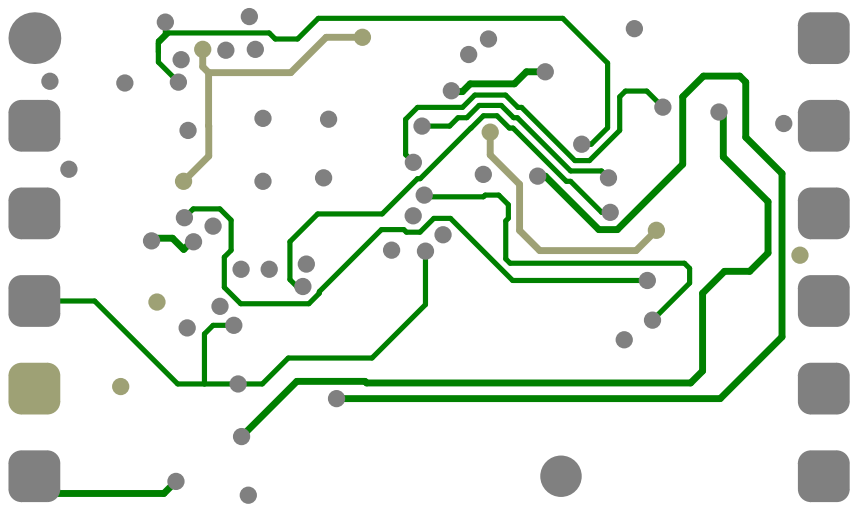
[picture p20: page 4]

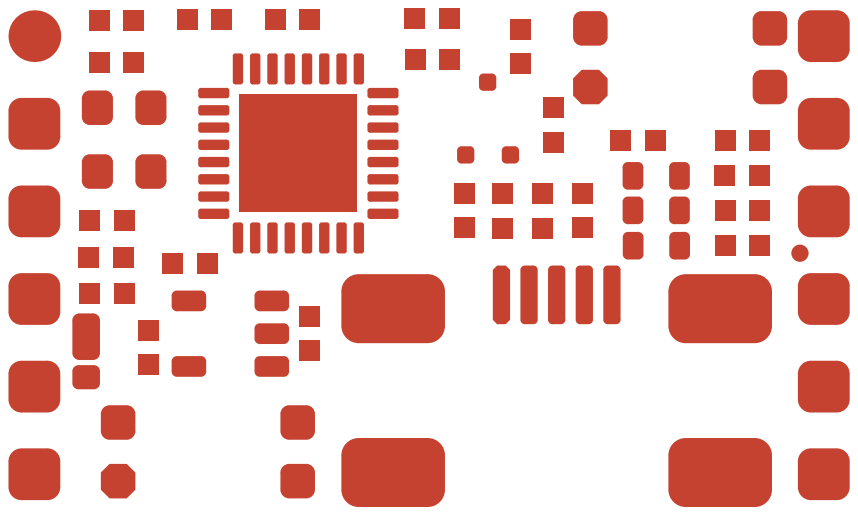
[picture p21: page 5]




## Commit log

2015-10-16 CREATED, ROUTED (TO CLEAN), BASED ON N-CPU1(N-U35)
    [N-DAP.PcbDoc, N-DAP.PrjPcb, N-DAP.SchDoc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]
2015-10-17 polished, dimensions uodated
    [N-DAP.PcbDoc, N-DAP.SchDoc]
2015-10-17 update and run all outjobs
    [N-DAP.GBL, N-DAP.GBO, N-DAP.GBP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]
2015-10-17 make all deliverables
    [BOTTOM.GBR, DIMENSIONS.GBR, MASK_BOTTOM.GBR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]
2015-10-17 Updates deliverable to pass eurocircuit visualizer. EUROCIRCUITS QUOTATION
    [BOTTOM.GBR, DIMENSIONS.GBR, MASK_BOTTOM.GBR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]
2015-10-19 pcb ReqForm signed
    [N-DAP.PcbDoc, N-DAP.PrjPcb, N-DAP.SchDoc]
2015-10-20 suppliers fields, mouser basket
    [N-DAP.PrjPcb, N-DAP.SchDoc, PurchaseList.csv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]
2015-10-23 gerber now with 4th missing layer added after eurocircuits exception
    [N-DAP.PcbDoc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]
2016-06-27 UPDATED SCHEMATIC LIBRARY OF MODULE
    [N-DAP.SchDoc]
2016-07-08 pinout spreadsheet and wiki update
    [N-DAP_PINOUT.xlsx]
2016-09-26 ISP & VARIANT
    ISP LINE PIN3 PULLED-UP, NOT FLOATING ANY MORE, R9 ADDED AND ROUTED
    R13 NOT PLACED IN NEW VARIANT "ASSEMBLY"
    [N-DAP.PrjPcb, N-DAP.SchDoc, N-DAP_PINOUT.xlsx]
2016-09-26 added TODO task in schematic
    [N-DAP.SchDoc]
2016-12-18 readme.md from mediawiki with pandoc
    [N-DAP_PINOUT.xlsx]
2017-01-26 N-BLOCKS SUBREPO
    [N-DAP.PrjPcb]
2017-02-10 libraries path
    [N-DAP.PrjPcb]
2017-03-07 integrate to n-blocks workspace
    [N-DAP.PrjPcb]
2017-05-11 board not anymore with half vias, (soldered pins were easy removing via!!)
2017-06-26 ADC0, ADC1 AND VBUS TO CONNECTOR, ALL 0603 AND CPU HAVE WIDER PADS, R13 NO-ASSEMBLY
    [N-DAP.SchDoc]
2017-06-26 TODO: TEST IF R9 FIXES THE "ALWAYS TO ISP AFTER RESET" ISSUE
    [N-DAP.SchDoc]
2017-06-26 N-DAP SCHLIB PART WITH ADC0,1 AND 5V-OUT
    [N-DAP.SchDoc]
2017-06-26 ALL OUTJOBS, make all deliverables, eurocircuits visulizer PASS and quotation
    [BOTTOM.GBR, DIMENSIONS.GBR, MASK_BOTTOM.GBR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]
2017-06-29 BOARD ORDERED
2017-09-07 n-PSU-LIN created and added as subrepo
    [N-DAP.SchDoc]
2017-09-12 N-MODBUS-W AND LIBRARY
    [N-DAP.SchDoc]
2017-10-17 Eurocircuits assembly output jobs
    [N-DAP.SchDoc, PartsList.xlsx, Pick_Place.csv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]
2017-10-18 Changed via hole size to pass eurocircuits inner anular ring Fixed supplier information for capacitors
    [N-DAP.PcbDoc, N-DAP.PrjPcb, N-DAP.SchDoc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]
2017-10-18 silkscreed N-DAP to new position, diode new footprint
    [N-DAP.PcbDoc, N-DAP.SchDoc]
2017-10-18 n-dap logo at Bottom Silkscreen
    [N-DAP.PcbDoc]
2017-10-26 COMPONENT DISTANCE AND BOARDOUTLINE ROOLS ACTIVATED,
    [N-DAP.PrjPcb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]
2017-10-27 run outjobs, make all deliverables, run replacer, update manually timestamped gerberfiles.zip, update eurocircuits (was waiting our reply)
    [BOTTOM.GBR, DIMENSIONS.GBR, MASK_BOTTOM.GBR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]
2017-10-31 red and green led supplier info change due to availablity. run BOM outjob
    [N-DAP.SchDoc, PurchaseList.xlsx]
2017-11-02 new quotation with missing assembly cost, waiting exception to be resolved. Gerber outjob include mechanical15 and gerber.cmd renames it to ASSEMBLY.GBR so ASSEMBLY.GBR is included in deliverable Ger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
    [BOTTOM.GBR, DIMENSIONS.GBR, MASK_BOTTOM.GBR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]
2017-11-02 add the 2 new files for ASSEMBLY
    [ASSEMBLY.GBR]
2018-01-03 schematic:comments on Buttons usage
    [N-DAP.SchDoc, N-DAP_PINOUT.xlsx]
2018-01-16 integrating n-test-rig and related modbus boards
    [N-DAP.SchDoc]
2018-06-18 SCHEMATIC: TEXT ON WHAT LINES CAN BE USED WITH PWM (MAT0,1 TIMER OUTPUTS)
    [N-DAP.SchDoc]
2018-06-18 ADDED TEXT AND LINK FROM MBED FORUM ON PWM LINES
    [N-DAP.SchDoc]
2019-04-26 A5 form factor
    [N-DAP.SchDoc]
2019-05-03 removed smd connectors, autoroute, TODO: finalize, gloss
    [Copy of N-DAP_with connectors.SchDoc, N-DAP.PcbDoc, N-DAP.SchDoc]
2020-01-13 new n-blocks template
    [Copy of N-DAP_with connectors.SchDoc, N-DAP.PcbDoc, N-DAP.SchDoc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]
2020-01-13 INITIAL SUBMISSION TO EUROCIRCUITS FOR V4: BASKET NO: B2205727
    [ASSEMBLY.GBR, BOTTOM.GBR, DIMENSIONS.GBR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]
2020-01-13 schematic color scheme black
    [N-DAP.PcbDoc, N-DAP.PrjPcb, N-DAP.SchDoc]
2020-01-13 revert to old smaller size, new aurocircuits basket number: B2205801
    [ASSEMBLY.GBR, BOTTOM.GBR, DIMENSIONS.GBR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]
2020-01-14 all resitors & capacitors from 0603 to 0402, new eurocircuits basket B2206781
    [ASSEMBLY.GBR, BOTTOM.GBR, DIMENSIONS.GBR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]
2020-01-15 BETA-LAYOUT QUOTATION
    [N-DAP.PrjPcb, N-DAP.SchDoc, PurchaseList.xlsx]
2020-01-24 update pcb and submit pcb file to betalayout
    [ASSEMBLY.GBR, BOTTOM.GBR, DIMENSIONS.GBR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]
2020-01-30 assembly file for betalayout
    [PurchaseList.xlsx]
2020-03-06 N-DAP SCHEMATIC LIB PART IS UPDATED IN SCHEMATIC WITH LPC11U35 PORT NUMBERS FRO ALL 9 GPIO PINS, EASIER TO USE FOR NON CMSIS-DAP USE CASES
    [N-DAP.PrjPcb, N-DAP.SchDoc]
2020-03-06 schematic color scheme changing to black
    [N-DAP.PrjPcb, N-DAP.SchDoc]
